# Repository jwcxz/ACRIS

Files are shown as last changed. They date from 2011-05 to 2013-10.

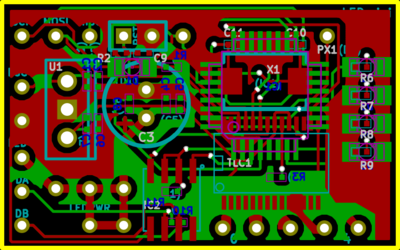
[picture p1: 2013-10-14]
boards/prj/ledmini/ledmini-brd_t.png

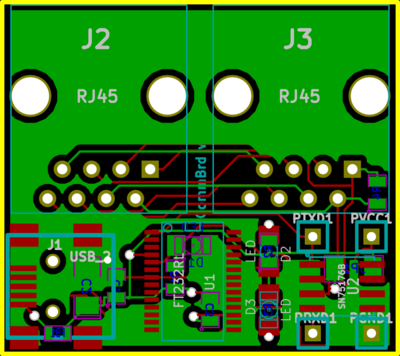
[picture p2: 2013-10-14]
boards/prj/commbrd/commbrd-brd_t.png

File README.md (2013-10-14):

ACRIS -- Advanced, Controllable Room Illumination System
========================================================

By JWC

Born out of a separate project I worked on over January and February of 2011,
[ACRIS] is a system designed to provide precise control of high-powered LEDs.
It consists of a set of LED controller boards, which drive LEDs using
constant-current sink drivers and are controlled over an RF network by a
transmitter.  This hardware is very easily controlled via simple serial
commands sent by software.

My goal for ACRIS is to provide a complete stack from base hardware to
software.

## Features

1.  Each LED controller supports up to 15 channels, with each channel sinking
    up to 360mA
2.  Each channel has 4096 levels of brightness
3.  LED controllers are around 2.3"x3.9"
4.  Status LEDs on the board show what the hell is going on
5.  LED controllers have a bootloader, so one can program new firmware to all
    devices on the bus easily.

## Repository Layout

The repository is laid out like this:

    avr     - firmware for ATmega micros on the LED controllers
    boards  - schematics and PCBs
    docs    - documents I've collected or written
    sw      - software for configuring and controlling the system

## Development

This repository has a lot of stuff that's continually being updated.  Current
effort is to convert the system to be wireless using the NRF24L01+ chip.  The
previous revision of this hardware communicated over an RS-485 network.  This,
as one might be able to imagine, proved to be really cumbersome.

[ACRIS]:http://jwcxz.com/projects/acris

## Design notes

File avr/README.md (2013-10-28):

ACRIS Firmware
==============

This directory contains firmware for the AVR MCU.  It is targeted at the
ATmega168.  The ATmega88 won't work because the bootloader is too big.

## Structure

    bld/        - configuration files for build
    inc/        - include files
    lib/        - library modules
    prj/        - projects
    Makefile    - rules for making projects from the fw dir
    README.md   - well, what are you reading?

## Projects

Projects are located in the `prj` dir.

    bootloader  - ACRIS bootloader (broken due to size issues)
    ledctrlr    - main LED controller firmware (getting there)
    rftxer      - wireless transmitter module (basic idea down)

    test-nrf    - first attempt at wireless communication with an NRF24L01+

    bootloader_uart - modified legacy bootloader that communicates over serial
    ledctrlr_uart   - modified legacy LED controller firmware, also serial

### Project structure

Each project includes:

    Makefile    - rules for making the project
    config.h    - master configuration file with project-specific rules
    pins.h      - project pinout
    main.c/h    - main project source
    README.md   - exactly what you would expect

## Libraries

There are also libraries.  In some cases, a single header can be supported by
multiple underlying designs.  Example: the `nrfspi_` module can either be
driven by the USART or the SPI module on the AVR.

    inc/ - include headers
    lib/ - library modules

    fn prefix   files       description
    __________  __________  __________________________________________________
    dbg_        dbg.h       control of board debug LEDs
                dbg.c

    eeprom_     eeprom.h    reading and writing settings in the EEPROM
                eeprom.c

    flash_      flash.h     flash memory access functions
                flash.c

    led_        led.h       action translator for LED array output
                led.c

    ledset_     ledset.h    functions for setting up TLC output buffer
                ledset.c

    nrf_        nrf.h       driver for NRF24L01+
                nrf.c

    nrfspi_     nrfspi.h    underlying data transfer layer between MCU and NRF
                nrfspi_spi.c      using HW SPI module
                nrfspi_usart.c    using USART in SPI master mode

    tlc_        tlc.h       driver for TLC5940
                tlc.c

    uart_       uart.h      UART communication layer
                uart.c

    uart_printf_    uart_printf.h   retargeting printf for uart output
                    uart_printf.c

    uart_rb_    uart_rb.h   ring-buffer com layer to make receiving streaming
                uart_rb.c   data easier

## Build

The `bld` directory contains the master rules for building projects.

## TODOs:
0.  Fix the wireless bootloader... it's too big for the flash.  This probably
    means an architectural change in reality, but at the very minimum involves
    statically linking to the end of the app-space flash or something stupid
    and dangerous like that.

1.  Install a shim between `nrf_` and the application layer to allow
    switching between wireless communication over NRF24L01+ and wired
    communication over RS-485.

2.  Add optional automatic retransmission support to the NRF driver.

3.  [partial] Update the bootloader to support wireless communication, with
    automatic retransmission to guarantee a good firmware load.

4.  Come up with a decent scheme for identifying all devices on the network and
    talking with each one of them (i.e. some kind of auto-discovery).  I have
    some ideas floating around in my head that make use of the multi-pipe
    features of the Nordic chips.

5.  Add training to startup to determine best communication channels; come up
    with a way to change network channels on the fly.

6.  Expand transmitter system to support multiple transmitters on a single host
    to boost throughput.  For extra lulz, make some run on the USART and others
    run on SPI and make the whole architecture event driven.

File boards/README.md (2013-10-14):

Electronics
===========

These schematics and boards were made with [KiCad].

## Boards

Board projects are in `prj/`.

    commbrd   - First attempt at a USB->RS485 converter
    commdngl  - USB-dongle that connects directly to a computer and delivers
                RS-485
    ecomm     - Etchable USB->RS485 converter (proven)
    ledctrlr  - The main ACRIS LED controller board
    ledmini   - Super tiny LED controller
    myropcb   - First run sent to Myro for production

## Libraries

Parts libraries (schematic symbols and footprints) are in the `libs/` dir.
Most of them are homemade, some of them are sourced from the internet.

## Tools

There are some scripts in the `tools/` dir.

    exportbom.sh  - Clean up exported BOM files
    package.sh    - Packager

### Packager
    
The packager does the following:

1.  Convert PS schematics exported from KiCad to PDF
2.  Convert SVG output from PCB editor to PNG
3.  Fix BOM headers with `exportbom.sh`
4.  Make image thumbnails.
5.  Archive Gerber and drill files
6.  Archive KiCad files 

[KiCad]:http://www.kicad-pcb.org/

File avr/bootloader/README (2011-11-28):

More information:
    http://jwcxz.com/projects/acris/bootloader.php

This bootloader provides the following features:
    1. fast startup time (i.e. bootloader->application time)
    2. downloading of program to device
    3. set address of instrument
    4. set the transmission baud rate (via the divisor)
    5. set a mask (only operate on some devices)
    6. view the instrument address on the debug LEDs
    7. program verification (not ready)

Transmission is done through a serial protocol:
    [SYNC][CMD][ARG0][ARG1]...[ARGn]

    Fn  Args    Description
    ___ _______ ____________________________________________________
    170 0       SYNC -- start of a packet

    N   0       NOP -- sent to wake bootloader up

    A   1       Set 1-byte address of the device in EEPROM

    B   2       [High][Low][Double?] -- set divisor and U2XN of the UART in EEPROM

    D   0       Show the high nibble of the instrument address on the debug LEDs

    E   0       Show the low nibble of the instrument address on the debug LEDs

    M   1       [InstAddr] Instrument address to work with for all following commands
                    0xFF - all instruments
                    0xF0-0xFE - blocks of 16

    P   2       [Addr][Page...] - Send program one page at a time
                    To simplify the bootloader, it does NOT take an Intel HEX
                    file as an input.  Rather, a special "program" script reads
                    the HEX file and outputs the following format:
                        [Starting Address][Page][Checksum]
                    The checksum is the one's complement of the sum of the
                    page stream.

                    Note: this means that the stream length depends on the page
                    size (whereas Intel HEX files have known lengths).
                    Furthermore, it requires that unused bytes be 0-filled or
                    something.  I'd rather make the programmer

    R   0       BOOT - boot the application

TODO:
    1.  Write the verification step
    2.  Allow reading bytes from EEPROM to debug LEDs
    3.  Decide whether to modify the bootloader to be able to write to and read
        from any EEPROM address

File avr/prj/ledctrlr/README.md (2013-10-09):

LED Controller Application
==========================

This is the main project of ACRIS: the firmware that runs on the LED drivers.
This version receives command packets via the UART.

## Protocol

The application-layer protocol format is: `[CMD][ARG0][ARG1]...[ARGn]`

    CMD  NAME  #ARGS ARGS / DESCRIPTION
    ____ _____ _____ _____________________________________________________
    0xAA LDSET 15    0RED 0GRN 0BLU 1RED 1GRN 1BLU ... 4RED 4GRN 4BLU
    0x00                8-bit control of each LED on the controller
                        enforces backwards compatibility with the existing
                        protocol (total 5*3*8=120 bits)
    0x01 HDSET  23   0000|0REDH 0REDL|0GRNH 0GRNL|0BLUH ...
                        12-bit packed control of each LED
                        (total 5*3*12=180 bits + 4 bits for alignment)
    0x10 LDALL  3    RED GRN BLU
                        8-bit control of all the LEDs on a given device
                        (total 3*8=24 bits)
    0x11 HDALL  5    0000|REDH REDL|GRNH ...
                        12-bit control of all the LEDs on a given device
                        (total 3*12=36 bits -> 40 bits with the firstmost
                        nibble ignored)

## Addressing

Addressing is handled in the communication layer.  It is `COM_AD_SIZE` bytes
long.  LED controllers are designed to be receivers.  Their addresses are set
in the bootloader by the EEPROM.  In the UART version, only the least
significant byte is minded.

## TODOs:

1.  Merge this into mainline wireless controller firmware and allow
    compile-time selection of the underlying communication system.

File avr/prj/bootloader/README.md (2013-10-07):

Bootloader Firmware
===================

In order to provide OTA firmware updates, I wrote a bootloader.  For more
information, see the [ACRIS bootloader page].

## Development Note

This project will require extensive modifications to support wireless
communication.  The existing wireless driver needs to support automatic
retransmission and have error modes that inform the master firmware updater
application of failures.

## Features

This bootloader provides the following features:

1.  Fast startup time (i.e. bootloader->application time)
2.  Downloading of program to device
3.  Set address of instrument
4.  Set the transmission baud rate (via the divisor)
5.  Set a mask (only operate on some devices)
6.  View the instrument address on the debug LEDs
7.  Program verification (not ready)

## Protocol

Transmission is done through a serial protocol, which looks like `[CMD][ARG0][ARG1]...[ARGn]`

    FN  ARGS    DESCRIPTION
    ___ _______ ____________________________________________________
    170 0       SYNC -- start of a packet

    N   0       NOP -- sent to wake bootloader up

    A   1       Set 1-byte address of the device in EEPROM

    B   2       [High][Low][Double?] -- set divisor and U2XN of the UART in EEPROM

    D   0       Show the high nibble of the instrument address on the debug LEDs

    E   0       Show the low nibble of the instrument address on the debug LEDs

    M   1       [InstAddr] Instrument address to work with for all following commands
                    0xFF - all instruments
                    0xF0-0xFE - blocks of 16

    P   2       [Addr][Page...] - Send program one page at a time
                    To simplify the bootloader, it does NOT take an Intel HEX
                    file as an input.  Rather, a special "program" script reads
                    the HEX file and outputs the following format:
                        [Starting Address][Page][Checksum]
                    The checksum is the one's complement of the sum of the
                    page stream.

                    Note: this means that the stream length depends on the page
                    size (whereas Intel HEX files have known lengths).
                    Furthermore, it requires that unused bytes be 0-filled or
                    something.  I'd rather make the programmer

    R   0       BOOT - boot the application

## TODOs:

1.  Enable automatic retransmission
2.  Allow reading bytes from EEPROM to debug LEDs
3.  Add ability to write to and read from any EEPROM address

[ACRIS bootloader page]:http://jwcxz.com/projects/acris/bootloader.php

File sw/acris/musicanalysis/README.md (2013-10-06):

Music Analysis
==============

This is a temporary holding directory for music analysis scripts.

there should be some sort of accessible backend that grabs an audio stream from
somewhere and converts it into a numpy array to be processed

then, there should be a series of processors that a plugin can take advantage
of.  maybe there should be some coarse-grained ones (dsp.howmuchbass()) and
some fine-grained ones (controllable-point fft)

FFT should be something to the effect of

1.  fill sample buffer
2.  apply windowing algorithm to sample set -- try hanning
3.  X = np.fft.rfft(windowed_data);
4.  Xdb = 20*np.log10(np.abs(X));
    
50% overlap between two sample buffers will likely work well

Testing with wave files:

    from scipy.io import wavfile
    fs, data = wavfile.read('/path/to/file.wav');

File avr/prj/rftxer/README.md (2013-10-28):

RF Transmitter
==============

This project essentially acts as a serial-to-RF transmitter.  Eventually it'll
be replaced by a true USB CDC module on a nice microprocessor, but for now, it
reads in a packet of data to send to a given address, and sends it.

## Protocol

The current protocol to transmit a packet is simply:

    [SYNC...][ADDR][PAYLOAD...]

The `[SYNC...]` header consists of `NUM_SYNCS` copies of `CMD_SYNC` to sync up
the serial stream.

The target address `[ADDR]` is a single byte (the LSB of the full address) for
now.  The full `COM_AD_SIZE` address space may be used later.

Since `[PAYLOAD...]` has a specific width (`COM_PL_SIZE`), the state machine is
pretty simple.

## Testing

The utility `sw/tests/nrf-dbg/nrf-txpld.py` sends test payloads to the
transmitter firmware.

## TODOs
    
1.  Allow enabling or disabling various features like auto-retransmit (useful
    for firmware updating, not useful for data streaming)

2.  Provide capability for LED controllers to report back their status in their
    ACK payloads and pass it up to the application layer.

3.  Lots of other stuff, like multiple-transmitter support.

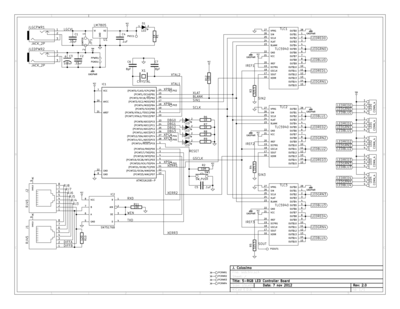
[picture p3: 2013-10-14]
boards/prj/ledctrlr/ledctrlr.png

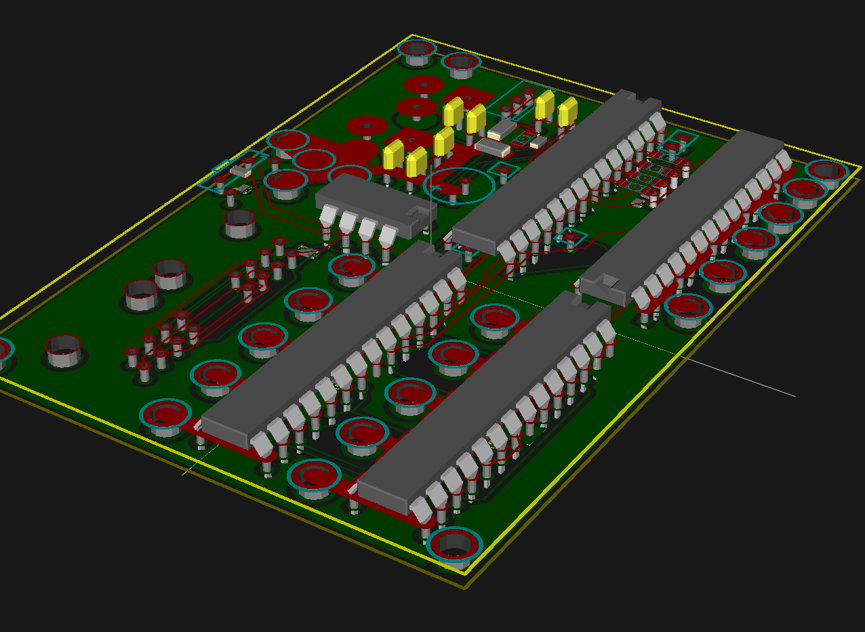
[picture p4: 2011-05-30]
boards/ledctrlr/ledctrlr-dip-routed.png

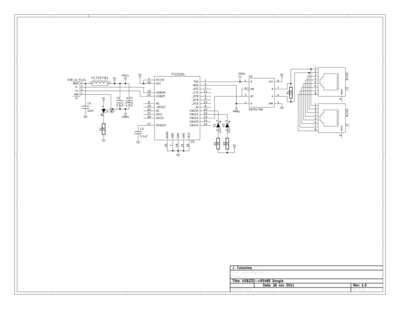
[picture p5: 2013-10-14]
boards/prj/commdngl/commdngl.png

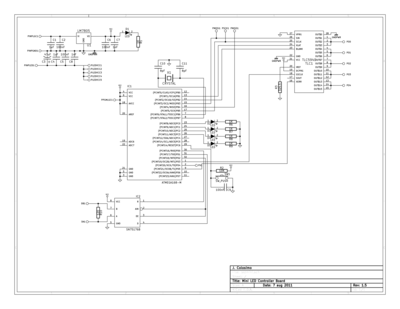
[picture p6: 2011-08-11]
boards/prj/ledmini/ledctrlr.png

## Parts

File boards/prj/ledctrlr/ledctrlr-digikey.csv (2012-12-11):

Digi-Key Part Number | Manufacturer | Manufacturer Part Number | Customer Reference | Quantity 1 | Quantity 2 | Quantity 3 | Description | Comments | RoHS Status | Lead Free Status | REACH Status
RMCF0805JT1K00CT-ND | STACKPOLE ELECTRONICS INC (VA) | RMCF0805JT1K00 | R1,6,7,8,9 | 50 | 0 | 0 | RES 1K OHM 1/8W 5% 0805 SMD |  | RoHS Compliant | Lead free | Unaffected Aug-2011
RMCF0805JT10K0CT-ND | STACKPOLE ELECTRONICS INC (VA) | RMCF0805JT10K0 | R2,11,12 | 50 | 0 | 0 | RES 10K OHM 1/8W 5% 0805 SMD |  | RoHS Compliant | Lead free | Unaffected Aug-2011
450-1662-ND | TE CONNECTIVITY ALCOSWITCH | FSMRA2JH | SW1 | 10 | 0 | 0 | SWITCH TACTILE SPST-NO 0.05A 12V |  | RoHS Compliant | Lead free | Unaffected Aug-2011
LM7805CT-ND | FAIRCHILD SEMICONDUCTOR | LM7805CT | U1 | 10 | 0 | 0 | IC REG LDO 5V 1A TO-220 |  | RoHS Compliant | Lead free | Unaffected Jun-2011
644-1026-1-ND | NDK (VA) | NX8045GB-20.000000MHZ | X1 | 10 | 0 | 0 | CRYSTAL 20.000000 MHZ 8PF SMD | Alternate Packaging Exists | RoHS Compliant | Lead free by exemption | Unaffected Nov-2011
445-1356-1-ND | TDK CORPORATION (VA) | C2012X7R1C334K/1.25 | C1,2 | 20 | 0 | 0 | CAP CER 0.33UF 16V 10% X7R 0805 |  | RoHS Compliant | Lead free | Unaffected Apr-2011
399-6103-ND | KEMET | ESK107M025AE3AA | C3 | 10 | 0 | 0 | CAP ALUM 100UF 25V 20% RADIAL |  | RoHS Compliant | Lead free | Unaffected Jan-2011
311-1361-1-ND | YAGEO (VA) | CC0805ZRY5V9BB104 | C4,5 | 25 | 0 | 0 | CAP CER 0.1UF 50V Y5V 0805 |  | RoHS Compliant | Lead free | Unaffected Sep-2011
311-1097-1-ND | YAGEO (VA) | CC0805DRNPO9BN8R0 | C6,7 | 25 | 0 | 0 | CAP CER 8PF 50V NPO 0805 |  | RoHS Compliant | Lead free | Unaffected Sep-2011
754-1142-1-ND | KINGBRIGHT CORP (VA) | APT3216SRCPRV | D1 | 10 | 0 | 0 | LED 3.2X1.6MM 640NM RED CLR SMD | Alternate Packaging Exists | RoHS Compliant | Lead free | Unaffected Feb-2011
754-1141-1-ND | KINGBRIGHT CORP (VA) | APT3216SGC | D2,3,4,5 | 50 | 0 | 0 | LED 3.2X1.6MM 568NM GRN CLR SMD |  | RoHS Compliant | Lead free | Unaffected Feb-2011
WM5572-ND | MOLEX CONNECTOR CORPORATION | 95501-2882 | J1,2 | 20 | 0 | 0 | CONN MOD JACK R/A 8P8C |  | RoHS Compliant | Lead free | Unaffected Dec-2009
CP-202A-ND | CUI INC | PJ-202A | JLGCPWER1,JLEDPWR2 | 20 | 0 | 0 | CONN POWER JACK 2.1MM PCB |  | RoHS Compliant | Lead free | Unaffected Oct-2010
ED2563-ND | ON SHORE TECHNOLOGY INC | OSTTA040161 | LED0,1,2,3,4 | 50 | 0 | 0 | TERMINAL BLOCK 5MM VERT 4POS PCB |  | RoHS Compliant | Lead free | Unaffected Aug-2011
RMCF0805JT330RCT-ND | STACKPOLE ELECTRONICS INC (VA) | RMCF0805JT330R | R3,4,5 | 50 | 0 | 0 | RES 330 OHM 1/8W 5% 0805 SMD |  | RoHS Compliant | Lead free | Unaffected Aug-2011
RMCF0805JT120RCT-ND | STACKPOLE ELECTRONICS INC (VA) | RMCF0805JT120R | R10 | 10 | 0 | 0 | RES 120 OHM 1/8W 5% 0805 SMD | Alternate Packaging Exists | RoHS Compliant | Lead free | Unaffected Aug-2011

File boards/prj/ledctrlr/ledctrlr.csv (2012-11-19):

Reference | Value | Footprint | Part | DigikeyPart | Field3 | Field4 | Field5 | Field6 | Field7 | Field8
C1 | .33uF | SM0805 | C2012X7R1C334K/1.25 | 445-1356-1-ND
C2 | .33uF | SM0805 | C2012X7R1C334K/1.25 | 445-1356-1-ND
C3 | 100uF | Elko_vert_DM7-5_RM2-5 | ESK107M025AE3AA | 399-6103-ND
C4 | .1uF | SM0805 | CC0805ZRY5V9BB104 | 311-1361-1-ND
C5 | .1uF | SM0805 | CC0805ZRY5V9BB104 | 311-1361-1-ND
C6 | 8pF | SM0805 | CC0805DRNPO9BN8R0 | 311-1097-1-ND
C7 | 8pF | SM0805 | CC0805DRNPO9BN8R0 | 311-1097-1-ND
D1 | LED | LED-1206-3D | APT3216SRCPRV | 754-1142-1-ND
D2 | LED | LED-1206-3D | APT3216SGC | 754-1141-1-ND
D3 | LED | LED-1206-3D | APT3216SGC | 754-1141-1-ND
D4 | LED | LED-1206-3D | APT3216SGC | 754-1141-1-ND
D5 | LED | LED-1206-3D | APT3216SGC | 754-1141-1-ND
IC1 | ATMEGA168-P | DIP-28__300 | ATMEGA168-20PU | ATMEGA168-20PU-ND
IC2 | SN75176B | SOIC8 | SN75176BP | 296-1739-5-ND
J1 | RJ45 | RJ45_8 | 95501-2882 | WM5572-ND
J2 | RJ45 | RJ45_8 | 95501-2882 | WM5572-ND
JLEDPWR2 | JACK_2P | JACK_ALIM | PJ-202A | CP-202A-ND
JLGCPWR1 | JACK_2P | JACK_ALIM | PJ-202A | CP-202A-ND
JP1 | JUMPER | SM1206 | N/A | N/A
LED0 | CONN_4 | OSTTA040161p | OSTTA040161 | ED2563-ND
LED1 | CONN_4 | OSTTA040161p | OSTTA040161 | ED2563-ND
LED2 | CONN_4 | OSTTA040161p | OSTTA040161 | ED2563-ND
LED3 | CONN_4 | OSTTA040161p | OSTTA040161 | ED2563-ND
LED4 | CONN_4 | OSTTA040161p | OSTTA040161 | ED2563-ND
PCRNR1 | CONN_1 | screw | N/A | N/A
PCRNR2 | CONN_1 | screw | N/A | N/A
PCRNR3 | CONN_1 | screw | N/A | N/A
PCRNR4 | CONN_1 | screw | N/A | N/A
PGND1 | CONN_1 | PAD | N/A | N/A
PPWR1 | CONN_1 | PAD
PSOUT1 | CONN_1 | PAD | N/A | N/A
PVCC1 | CONN_1 | PAD
PX1 | CONN_1 | PAD | N/A | N/A
PX2 | CONN_1 | PAD | N/A | N/A
PX3 | CONN_1 | PAD | N/A | N/A
PX4 | CONN_1 | PAD | N/A | N/A
PX5 | CONN_1 | PAD | N/A | N/A
R1 | 1K | SM0805 | RMCF0805JT1K00 | RMCF0805JT1K00CT-ND
R2 | 10K | SM0805 | RMCF0805JT10K0 | RMCF0805JT10K0CT-ND
R3 | 325.5 | SM0805 | RMCF0805JT330R | RMCF0805JT330RCT-ND
R4 | 325.5 | SM0805 | RMCF0805JT330R | RMCF0805JT330RCT-ND
R5 | 325.5 | SM0805 | RMCF0805JT330R | RMCF0805JT330RCT-ND
R6 | 1K | SM0805 | RMCF0805JT1K00 | RMCF0805JT1K00CT-ND
R7 | 1K | SM0805 | RMCF0805JT1K00 | RMCF0805JT1K00CT-ND
R8 | 1K | SM0805 | RMCF0805JT1K00 | RMCF0805JT1K00CT-ND
R9 | 1K | SM0805 | RMCF0805JT1K00 | RMCF0805JT1K00CT-ND
R10 | 120 | SM0805 | RMCF0805JT120R | RMCF0805JT120RCT-ND
R11 | 10K | SM0805 | RMCF0805JT10K0 | RMCF0805JT10K0CT-ND
R12 | 10K | SM0805 | RMCF0805JT10K0 | RMCF0805JT10K0CT-ND
SW1 | SW_PUSH | PUSH_SW | FSMRA2JH | 450-1662-ND
TLC1 | TLC5940 | DIP-28__300 | TLC5940NT | 296-17732-5-ND
TLC2 | TLC5940 | DIP-28__300 | TLC5940NT | 296-17732-5-ND
TLC3 | TLC5940 | DIP-28__300 | TLC5940NT | 296-17732-5-ND
U1 | LM7805 | LM78XXV-3D | LM7805CT | LM7805CT-ND
X1 | CRYSTAL | Crystal_FOX-FE_SMD_RevA_09Aug2010 | NX8045GB-20.000000MHZ | 644-1026-1-ND

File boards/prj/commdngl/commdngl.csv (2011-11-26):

Reference | Value | Footprint | Part | DigikeyPart
C1 | 0.1uF | SM0805 | CC0805ZRY5V9BB104 | 311-1361-1-ND
C2 | 4.7uF | SM0805 | F921A475MPA | 493-2333-1-ND
C3 | 0.1uF | SM0805 | CC0805ZRY5V9BB104 | 311-1361-1-ND
C4 | 10nF | SM0603 | C1608X7R1H103K | 445-1311-1-ND
D1 | LED | SM1206 | APT3216SRCPRV | 754-1142-1-ND
D2 | LED | LED-1206 | APT3216SGC | 754-1141-1-ND
D3 | LED | LED-1206 | APT3216SGC | 754-1141-1-ND
FB1 | FILTER | SM0603 | MMZ1608S400A | 445-2183-1-ND
J1 | USB-A-PLUG | USB-A-PLUG | 48037-0001 | WM17117-ND
J2 | RJ45 | RJ45_8
J3 | RJ45 | RJ45_8 | 95501-2882 | WM5572-ND
PGND1 | CONN_1 | SIL-1 | N/A | N/A
PRXD1 | CONN_1 | SIL-1 | N/A | N/A
PTXD1 | CONN_1 | SIL-1 | N/A | N/A
PVCC1 | CONN_1 | SIL-1 | N/A | N/A
R1 | 1K | SM0805 | RMCF0805JT1K00 | RMCF0805JT1K00CT-ND
R2 | 1K | SM0805 | RMCF0805JT1K00 | RMCF0805JT1K00CT-ND
R3 | 1K | SM0805 | RMCF0805JT1K00 | RMCF0805JT1K00CT-ND
R4 | 120 | SM0805 | RMCF0805JT120R | RMCF0805JT120RCT-ND
U1 | FT232RL | SSOP28 | FT232RL-REEL | 768-1007-1-ND
U2 | SN75176B | SOIC8 | SN75176BPSR | 296-27995-1-ND

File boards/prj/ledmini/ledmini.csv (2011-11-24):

Reference | Value | Footprint | Part | DigikeyPart
C1 | 1uF | SM0402 | C1005X5R0J105M | 445-1415-1-ND
C2 | 100nF | SM0402 | C1005Y5V1E104Z | 445-3445-1-ND
C3 | 47uF | Elko_vert_DM7-5_RM2-5 | ECA-1CM470 | P5137-ND
C4 | 1uF | SM0402 | C1005X5R0J105M | 445-1415-1-ND
C5 | 100nF | SM0402 | C1005Y5V1E104Z | 445-3445-1-ND
C6 | 100nF | SM0402 | C1005Y5V1E104Z | 445-3445-1-ND
C7 | 1nF | SM0402 | C1005X7R1H102K | 445-1256-1-ND
C8 | 1nF | SM0402 | C1005X7R1H102K | 445-1256-1-ND
C9 | 100nF | SM0402 | C1005Y5V1E104Z | 445-3445-1-ND
C10 | 8pF | SM0402 | C1005C0G1H080D | 445-4891-1-ND
C11 | 8pF | SM0402 | C1005C0G1H080D | 445-4891-1-ND
D1 | LED | LED-1206 | APT3216SRCPRV | 754-1142-1-ND
D2 | LED | LED-1206 | APT3216SGC | 754-1141-1-ND
D3 | LED | LED-1206 | APT3216SGC | 754-1141-1-ND
D4 | LED | LED-1206 | APT3216SGC | 754-1141-1-ND
D5 | LED | LED-1206 | APT3216SGC | 754-1141-1-ND
DA1 | CONN_1 | 1pin | N/A | N/A
DB1 | CONN_1 | 1pin | N/A | N/A
IC1 | ATMEGA168-M | TQFP32 | ATMEGA168P-20AU | ATMEGA168P-20AU-ND
IC2 | SN75176B | SOIC8 | SN75176BD | 296-1275-5-ND
PINPGND1 | CONN_1 | 1pin | N/A | N/A
PINPLED1 | CONN_1 | 1pin | N/A | N/A
PINPLGC1 | CONN_1 | 1pin | N/A | N/A
PLEDVCC1 | CONN_1 | SIL-1 | N/A | N/A
PLEDVCC2 | CONN_1 | SIL-1 | N/A | N/A
PLEDVCC3 | CONN_1 | SIL-1 | N/A | N/A
PLEDVCC4 | CONN_1 | SIL-1 | N/A | N/A
PLEDVCC5 | CONN_1 | SIL-1 | N/A | N/A
PMISO1 | CONN_1 | SIL-1 | N/A | N/A
PMOSI1 | CONN_1 | SIL-1 | N/A | N/A
PO0 | CONN_1 | 1pin | N/A | N/A
PO1 | CONN_1 | 1pin | N/A | N/A
PO2 | CONN_1 | 1pin | N/A | N/A
PO3 | CONN_1 | 1pin | N/A | N/A
PO4 | CONN_1 | 1pin | N/A | N/A
PPGMLGC1 | CONN_1 | 1pin | N/A | N/A
PSCK1 | CONN_1 | SIL-1 | N/A | N/A
PX1 | CONN_1 | SIL-1 | N/A | N/A
R1 | 1K | SM0402 | RMCF0402JT1K00 | RMCF0402JT1K00CT-ND
R2 | 10K | SM0402 | RMCF0402JT10K0 | RMCF0402JT10K0CT-ND
R3 | 325.5 | SM0402 | P330JCT-ND | ERJ-2GEJ331X
R6 | 1K | SM0402 | RMCF0402JT1K00 | RMCF0402JT1K00CT-ND
R7 | 1K | SM0402 | RMCF0402JT1K00 | RMCF0402JT1K00CT-ND
R8 | 1K | SM0402 | RMCF0402JT1K00 | RMCF0402JT1K00CT-ND
R9 | 1K | SM0402 | RMCF0402JT1K00 | RMCF0402JT1K00CT-ND
R10 | 120 | SM0402 | ERJ-2GEJ121X | P120JCT-ND
R11 | 10K |  | RMCF0402JT10K0 | RMCF0402JT10K0CT-ND
SW1 | SW_PUSH | PUSH_SW | FSMRA2JH | 450-1662-ND
TLC1 | TLC5940 | SSOP28 | TLC5940PWP | 296-17733-5-ND
U1 | LM7805 | LM78XXV | LM7805CT | LM7805CT-ND
X1 | CRYSTAL | Crystal_FOX-FE_SMD_RevA_09Aug2010 | NX8045GB-20.000000MHZ | 644-1026-1-ND

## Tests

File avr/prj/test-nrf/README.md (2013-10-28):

Test FW: Wireless Communication
===============================

This is a highly-configurable testing firmware that interacts with the
NRF24L01+ to send or receive data.  The relative build parameters to pass to
`make` are `MODE` and `TRGT`.

## Transmitter target

When building with `MODE=tx TRGT=breadboard` (`TRGT=ledctrlr` untested),
firmware that simply sends payloads of incrementing values to the fixed
receiver address of `0xAAAA01`.  The transmitter's own address is `0x555501`,
but this is irrelevant.

## Receiver target

The receiver listens for incoming packets and happily blinks LEDs when it
receives them.  There are two options for building with `MODE=rx`.

### Breadboard setup

Building with `TRGT=breadboard` produces firmware that is designed to operate
with the NRF24L01+ on the eral SPI bus and a serial console on the UART.  A
serial bootloader must be installed on the chip.

The firmware spits out received packets to the UART for inspection.
`sw/tests/nrf-dbg/nrf-cap.py` is useful here.

### Reworked ACRIS board setup

Building with `TRGT=ledctrlr` produces firmware that is designed for reworked
ACRIS LED controllers.  The NRF24L01+ is attached to the USART and the boards
are programmed directly over JTAG.

Therefore, no UART output is available, but you can watch the debug LEDs
happily blink received packets.

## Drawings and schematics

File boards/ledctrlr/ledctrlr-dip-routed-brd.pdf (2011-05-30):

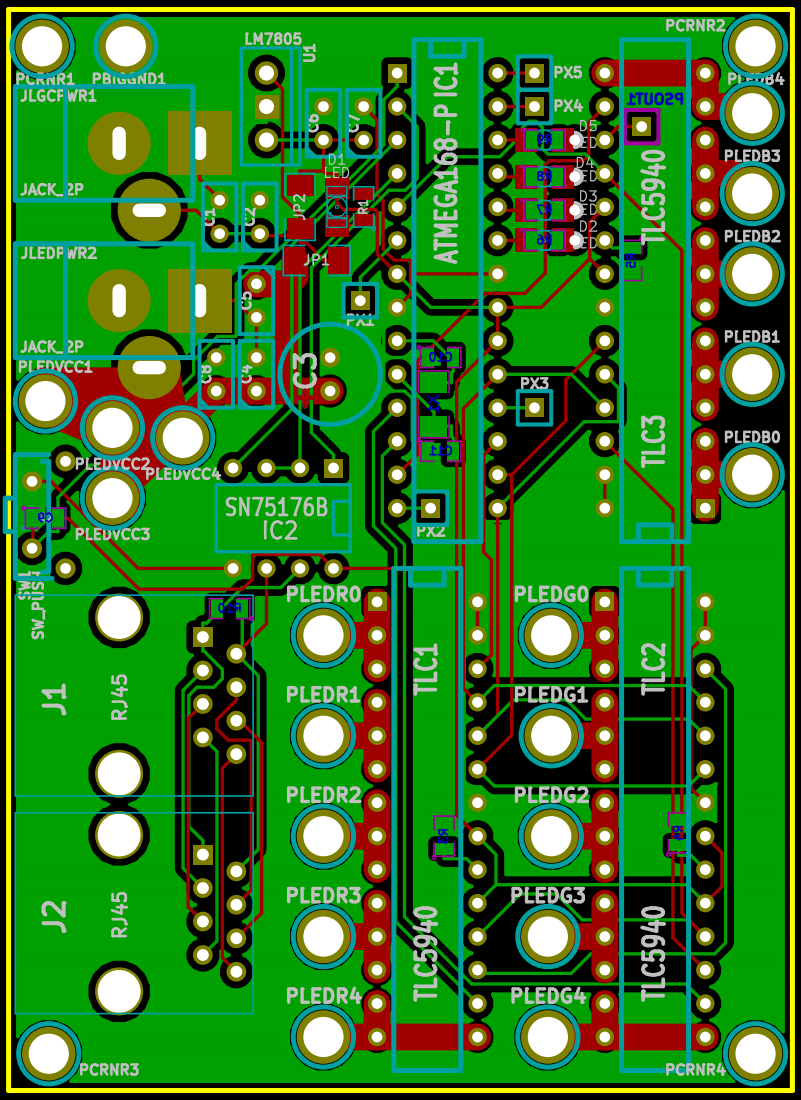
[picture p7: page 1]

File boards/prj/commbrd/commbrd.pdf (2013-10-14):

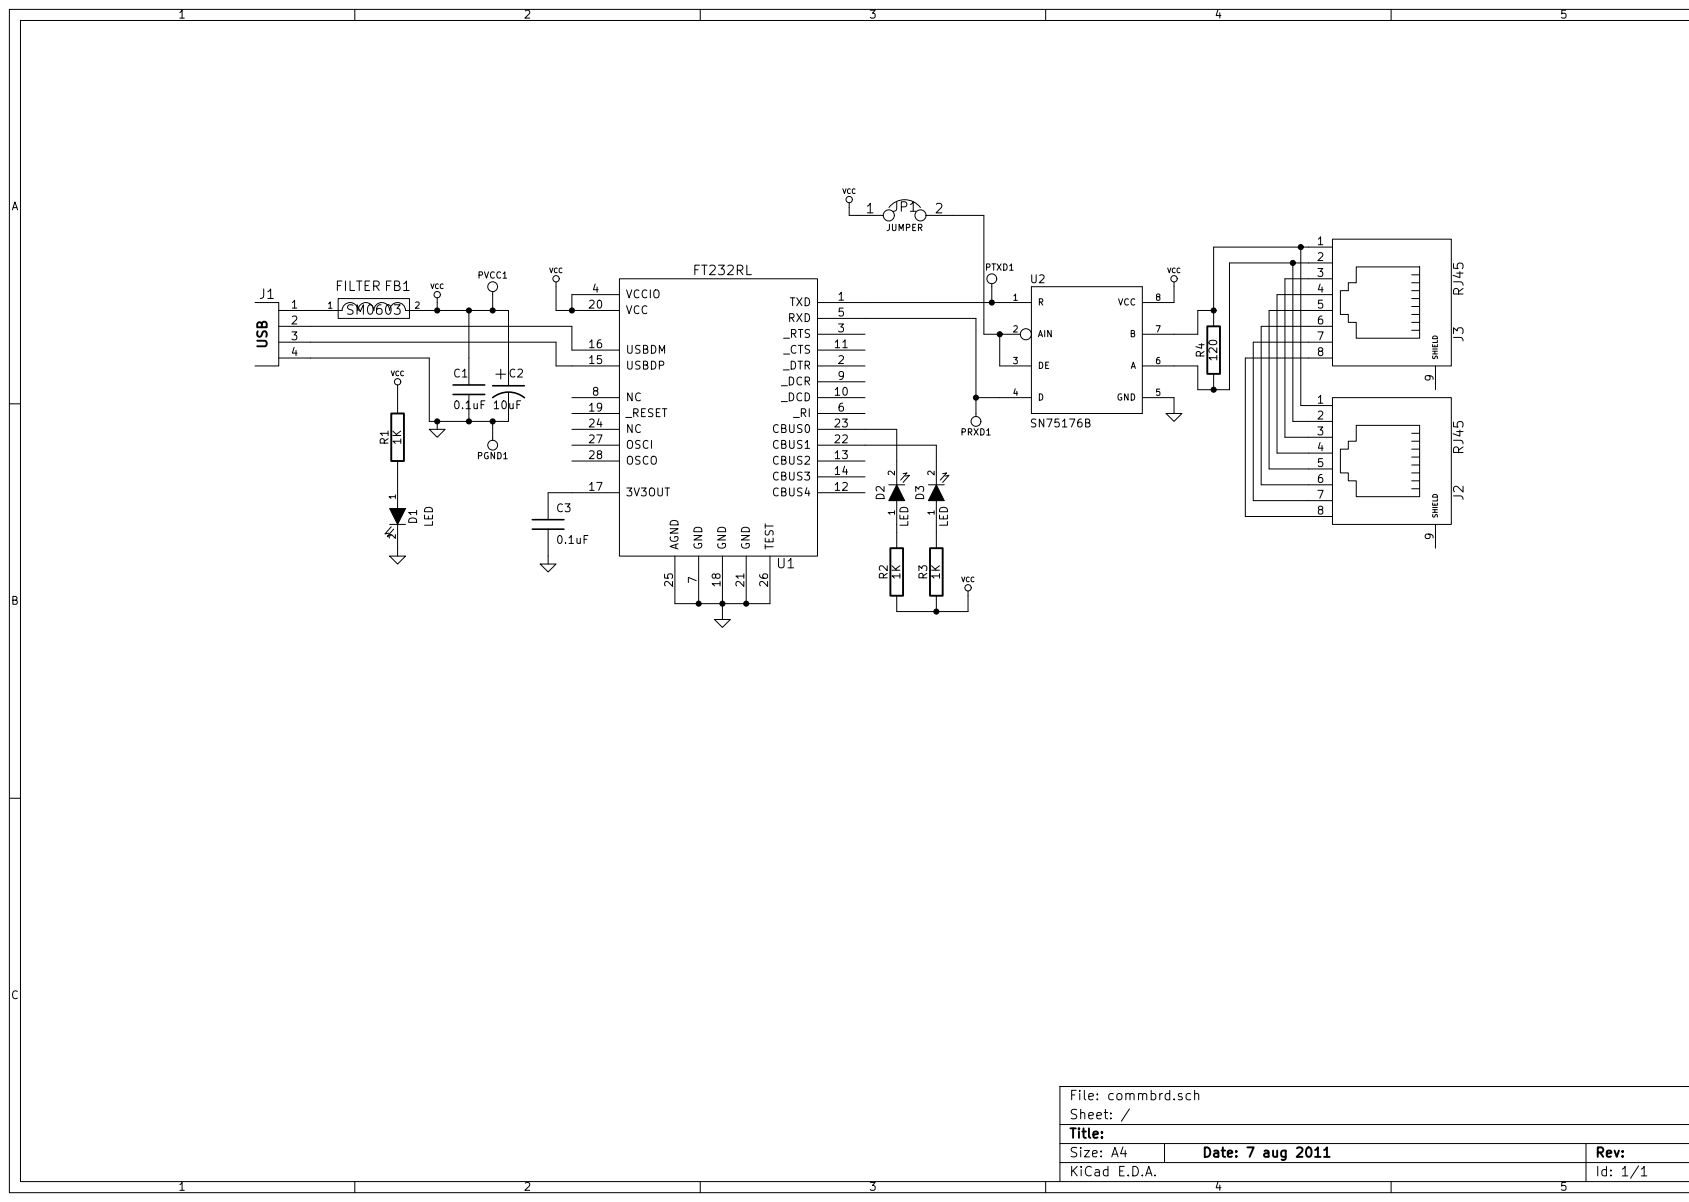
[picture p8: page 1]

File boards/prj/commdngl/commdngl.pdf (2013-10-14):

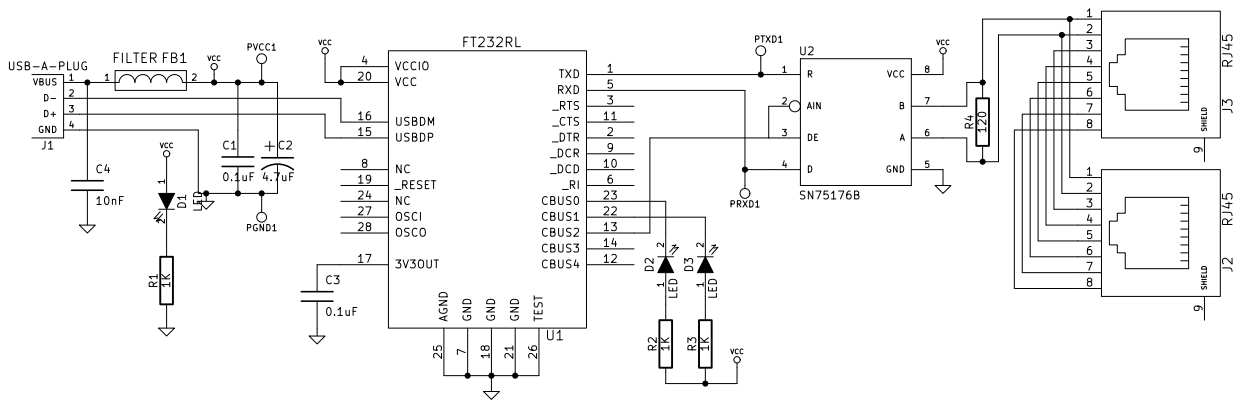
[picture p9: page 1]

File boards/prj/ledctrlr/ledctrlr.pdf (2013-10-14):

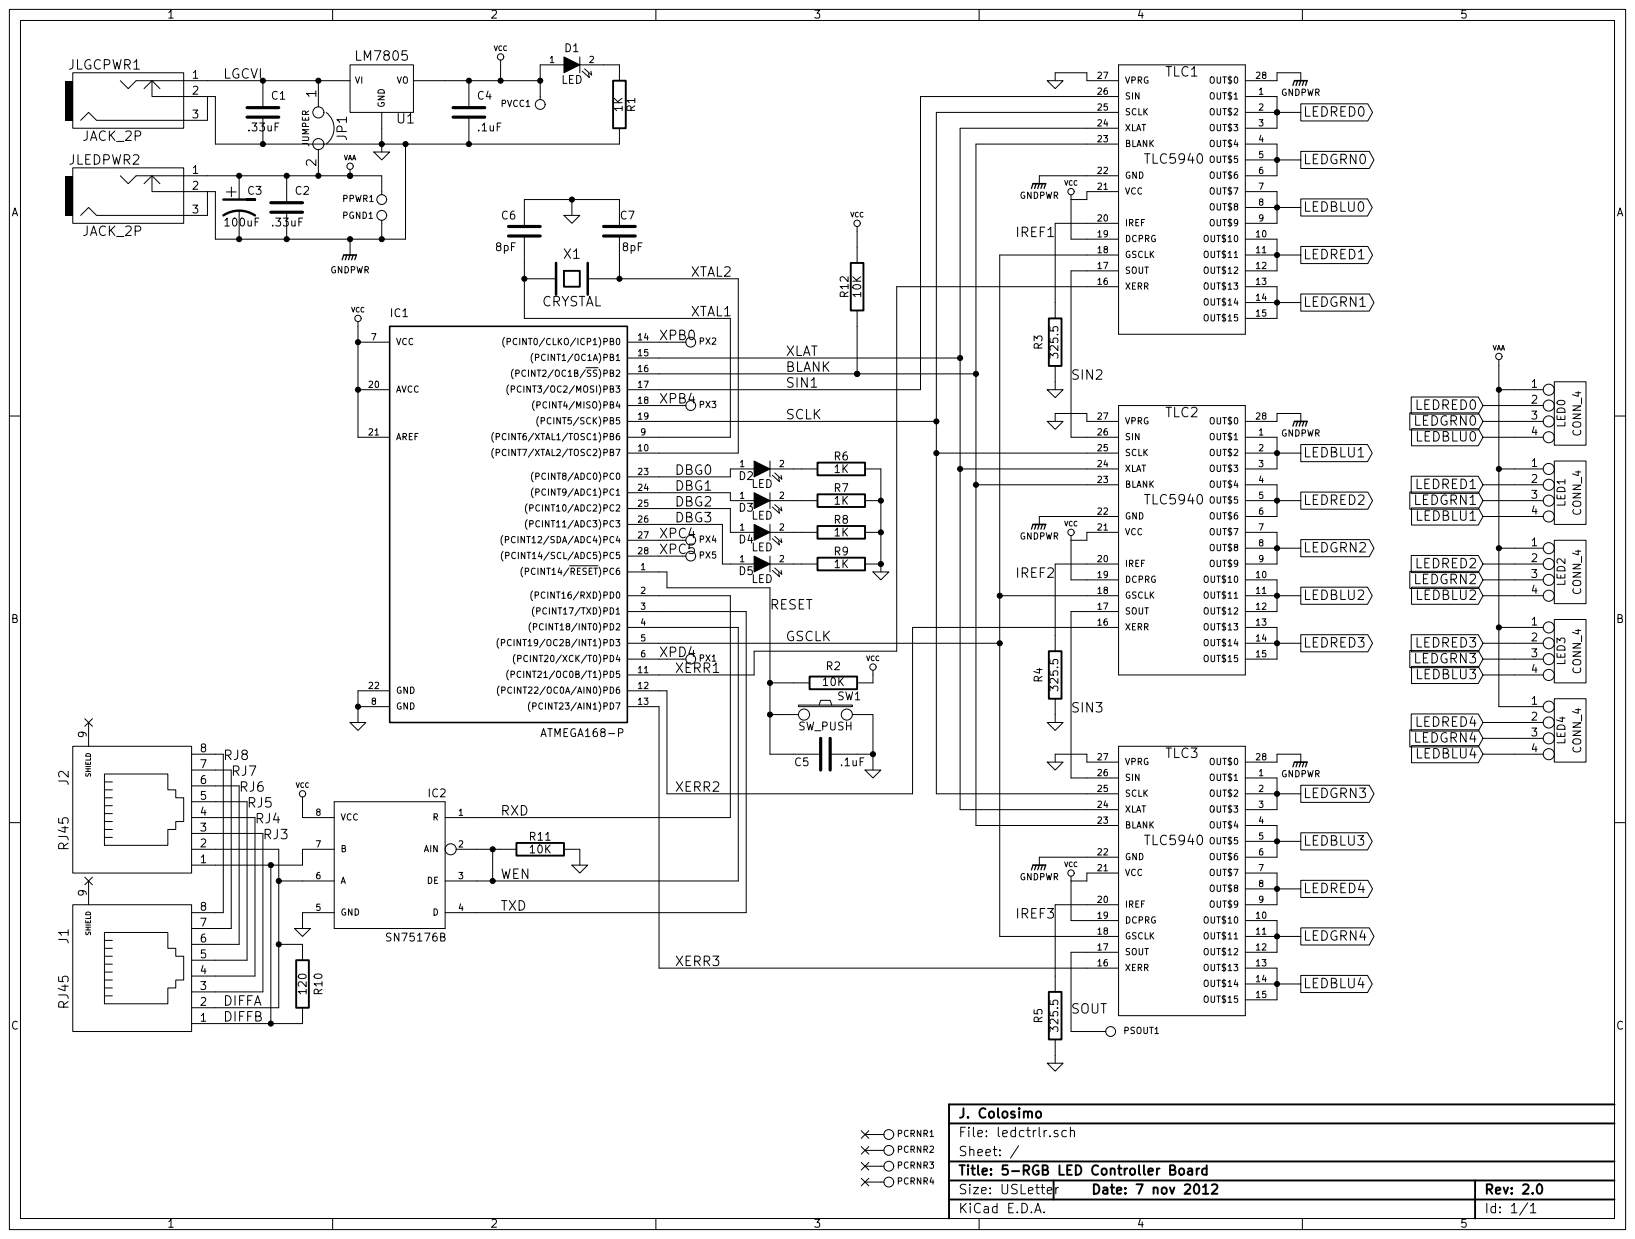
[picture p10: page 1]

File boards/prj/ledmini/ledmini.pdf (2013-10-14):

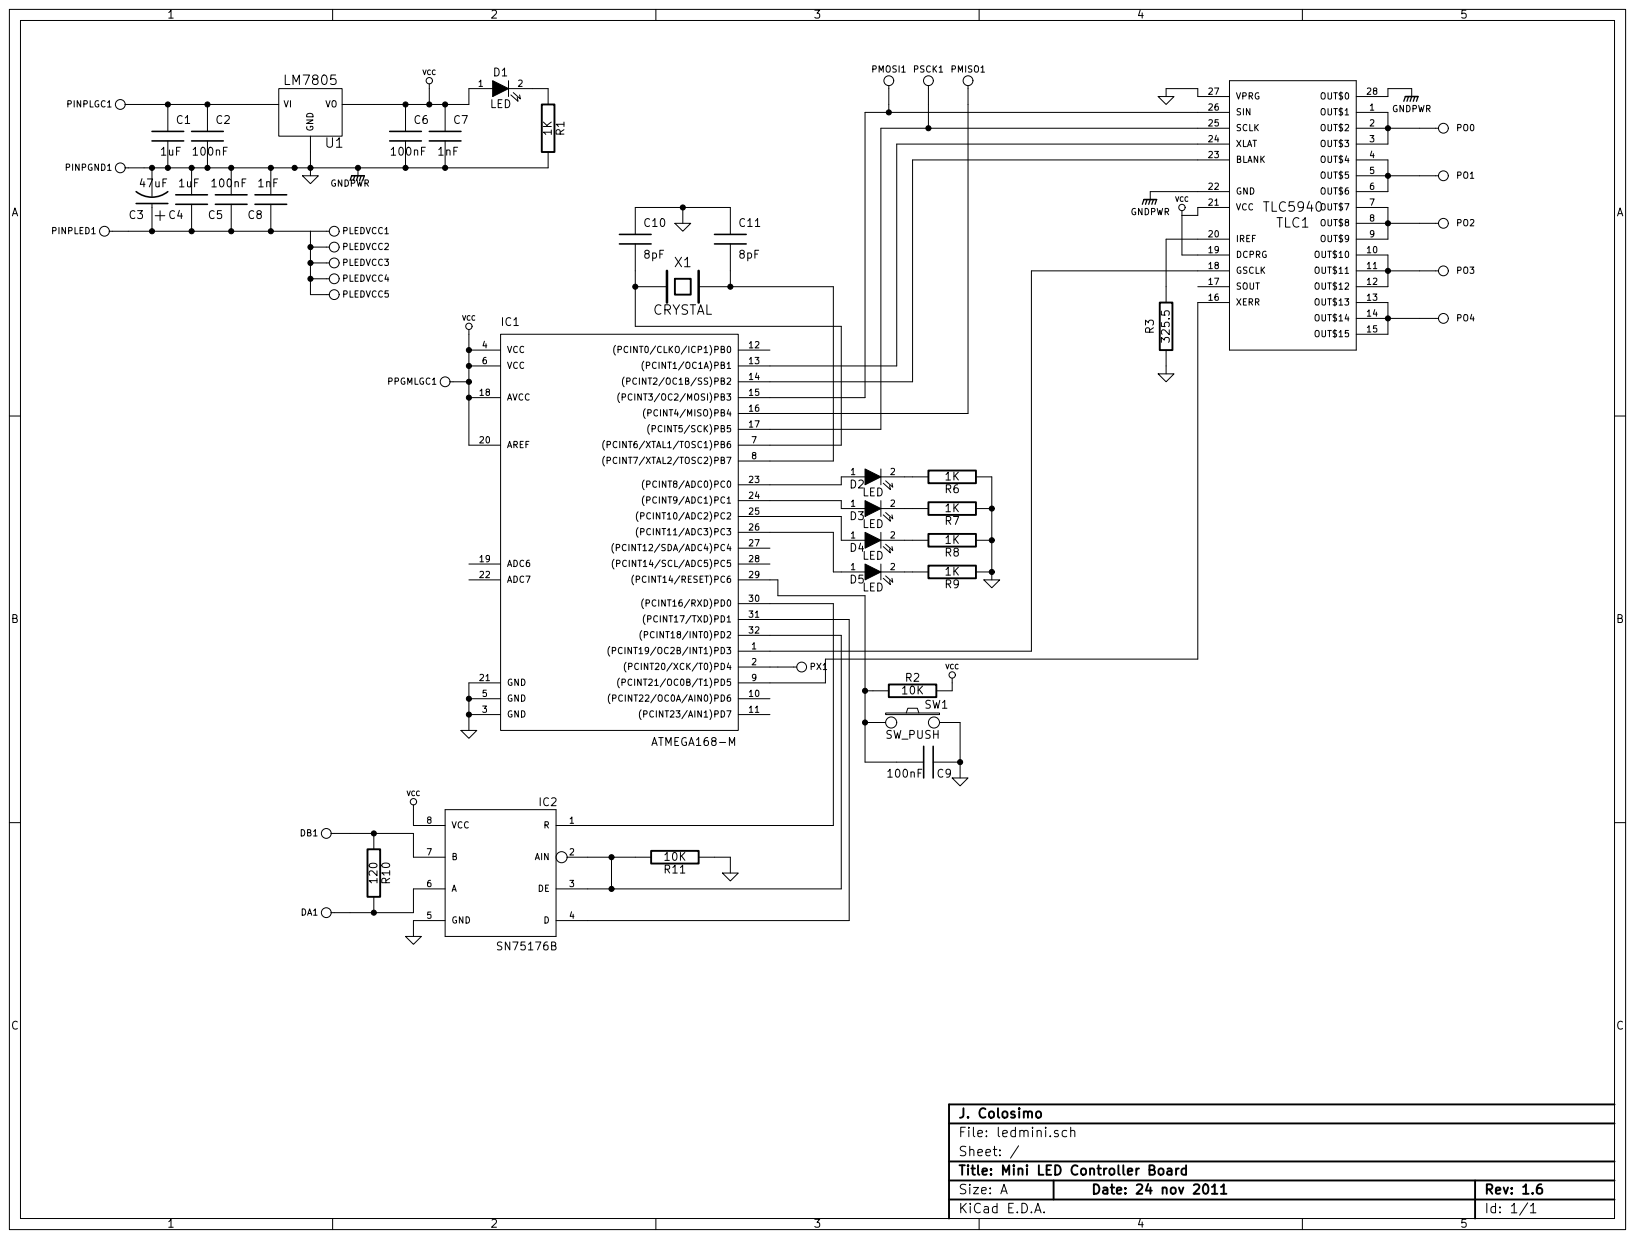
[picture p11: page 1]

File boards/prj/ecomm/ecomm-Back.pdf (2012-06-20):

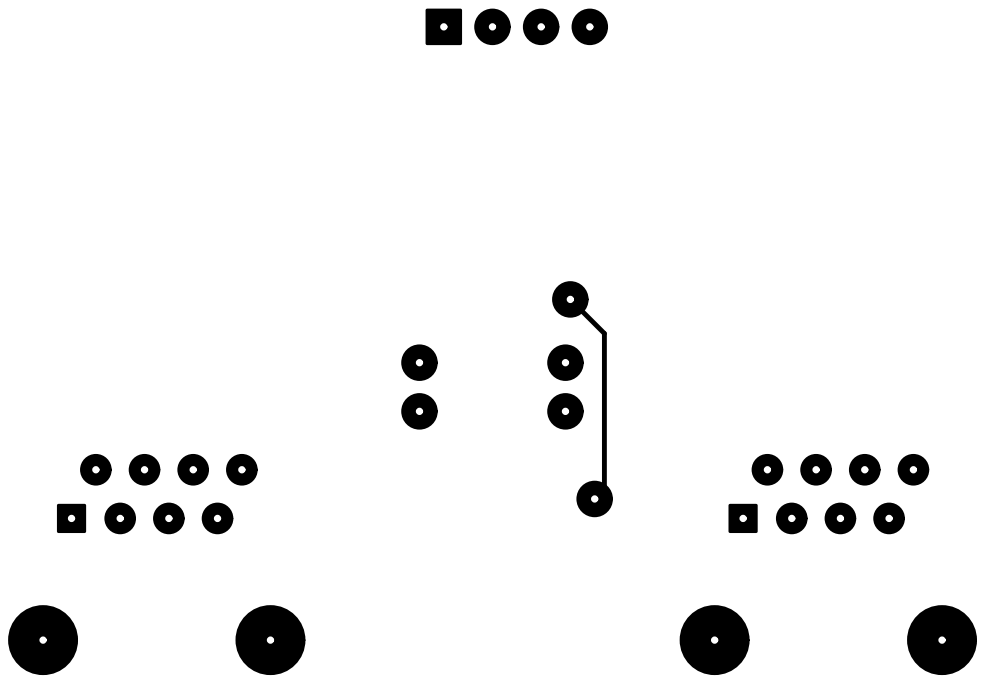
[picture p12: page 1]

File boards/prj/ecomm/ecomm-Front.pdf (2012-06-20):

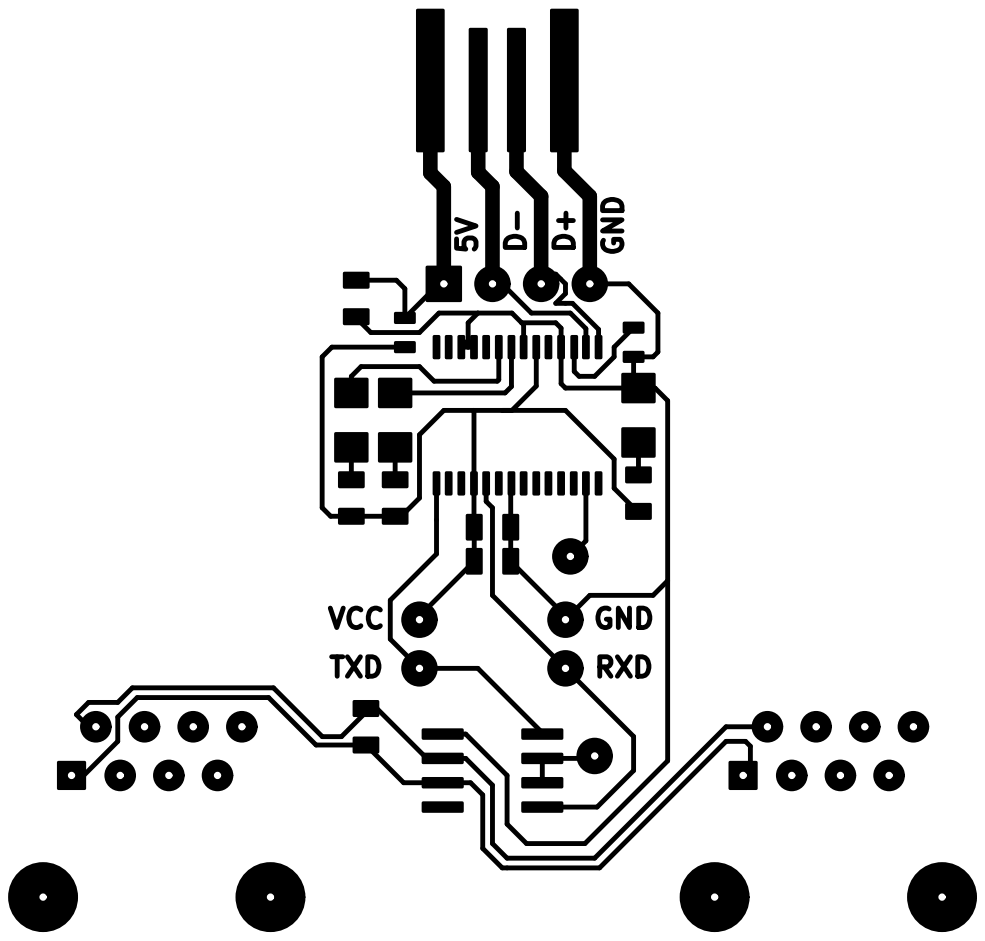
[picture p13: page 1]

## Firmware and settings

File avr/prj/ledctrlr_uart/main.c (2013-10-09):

/* A C R I S   P R O J E C T
 * LED Controller Firmware
 * http://jwcxz.com/projects/acris
 * jwc :: jwcxz.com
 */

#include "config.h"

#include <inttypes.h>
#include <util/delay.h>
#include <avr/io.h>
#include <avr/interrupt.h>
#include <avr/pgmspace.h>
#include <avr/boot.h>
#include <avr/eeprom.h>

#include "main.h"

#include "dbg.h"
#include "eeprom.h"
#include "led.h"
#include "tlc.h"
#include "uart.h"
#include "uart_rb.h"

uint8_t my_addr_full[3];
uint8_t my_addr;

// TODO: un-extern this
uint8_t tlc[3][24];

uint8_t action;         // current action
uint8_t numargs;        // number of arguments to expect
uint8_t args[MAXARGS];  // array to store arguments
uint8_t *argptr = args; //   ... associated pointer

static uint8_t cmdstate;

int main(void) {
    // initialize debug LEDs
    dbg_init();
    dbg_set(0x8);

    // initialize TLC
    tlc_init();
    // set everything off
    //tlc_drive();

    // get the address of the device
    eeprom_get_addr(my_addr_full);
    my_addr = my_addr_full[0];

    // initialize UART
    uart_rb_init();
    
    // enable interrupts
    sei();

    while (1) {
        if ( uart_rb_data_rdy() ) {
            receive_data();
        }
    }

	return 0;
}

void receive_data(void) {
    unsigned char inbyte;

    inbyte = uart_rb_rx();

    if ( inbyte == CMD_SYNC )  {
        // the sync byte is always treated as a trigger to reset the state
        // machine -- never send it as an argument
        cmdstate = CST_SYNC;
    } else {
        switch (cmdstate) {
            case CST_IDLE:
                cmdstate = CST_IDLE;
                break;
                
            case CST_SYNC:
                // save command for later processing
                action = inbyte;
                
                // reset arg pointer
                argptr = args;

                switch (inbyte) {
                    case CMD_LDSET:
                    case CMD_LDSET_LEGACY:
                        dbg_set(0x4);
                        action = CMD_LDSET; // replace legacy action code
                        numargs = 16;
                        cmdstate = CST_ARGS;
                        break;

                    case CMD_HDSET:
                        dbg_set(0x4|0x1);
                        numargs = 24;
                        cmdstate = CST_ARGS;
                        break;

                    case CMD_LDALL:
                        dbg_set(0x2);
                        numargs = 24;
                        numargs = 4;
                        cmdstate = CST_ARGS;
                        break;

                    case CMD_HDALL:
                        dbg_set(0x2|0x1);
                        numargs = 6;
                        cmdstate = CST_ARGS;
                        break;
                        
                    case CMD_STATS:
                        dbg_set(0x8);
                        numargs = 1;
                        cmdstate = CST_ARGS;
                        break;

                    default:
                        cmdstate = CST_IDLE;
                        break;
                }
                break;

            case CST_ARGS:
                *argptr++ = inbyte;

                if ( argptr - args == numargs ) {
                    // all arguments collected
                    // perform appropriate action
                    
#if 1
                    led_action(action, args);
#else
                    if (action == CMD_STATS) {
                        // send back system status
                        if (my_addr == args[0]) {
                            uart_tx(tlc_read_xerr());
                        }
                    } else {
                        led_action(action, args);
                    }
#endif

                    cmdstate = CST_IDLE;
                } else {
                    cmdstate = CST_ARGS;
                }
                break;

            default:
                // the hell!?
                cmdstate = CST_IDLE;
                break;
        }
    }
}

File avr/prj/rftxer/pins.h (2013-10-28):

#ifndef __PINS_H_
#define __PINS_H_


// UART
#define UART_TX_PIN  PD1
#define UART_TX_PRT  PORTD
#define UART_TX_DDR  DDRD

#define UART_RX_PIN  PD0
#define UART_RX_PRT  PORTD
#define UART_RX_DDR  DDRD


// NRF24L01+ control and data
// IRQ
#define NRF_IRQ_PIN  PD2
#define NRF_IRQ_PRT  PORTD
#define NRF_IRQ_DDR  DDRD

// chip enable
#define NRF_CE_PIN   PB0
#define NRF_CE_PRT   PORTB
#define NRF_CE_DDR   DDRB

// SPI CS_L
#define NRF_CSN_PIN  PC4
#define NRF_CSN_PRT  PORTC
#define NRF_CSN_DDR  DDRC

// MISO
#define NRF_MISO_PIN PB4
#define NRF_MISO_PRT PORTB
#define NRF_MISO_DDR DDRB

// MOSI
#define NRF_MOSI_PIN PB3
#define NRF_MOSI_PRT PORTB
#define NRF_MOSI_DDR DDRB

// SCLK
#define NRF_SCLK_PIN PB5
#define NRF_SCLK_PRT PORTB
#define NRF_SCLK_DDR DDRB

// SS
#define NRF_CSEL_PIN PB2
#define NRF_CSEL_PRT PORTB
#define NRF_CSEL_DDR DDRB


// debug
#define DBGLED_MSK  0x0F
#define DBGLED_PRT  PORTC
#define DBGLED_DDR  DDRC


#endif

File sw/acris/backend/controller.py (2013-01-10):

from backend.network import Commands as cmd
import backend.utils

class Controller:
    mode = "ld";

    def __init__(self, network, address):
        self.network = network; # serial connection
        self.address = address; # device address
        
    def set_mode(self, newmode):
        if newmode == "hd":
            self.mode = "hd";
        elif newmode == "ld":
            self.mode = "ld";

    def set(self, args):
        if self.mode == "ld":
            self.ldset(args);
        else:
            self.hdset(args);

    def hdset(self, args):
        packedargs = backend.utils.hdpack(args);
        self.network.cmd([cmd.HDSET, self.address]+packedargs);

    def ldset(self, args):
        packedargs = [];

        for i in xrange(5):
            packedargs.extend(args[i]);

        self.network.cmd([cmd.LDSET, self.address]+packedargs);

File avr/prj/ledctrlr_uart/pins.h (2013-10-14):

#ifndef __PINS_H_
#define __PINS_H_


// UART communication
#define UART_TX_PIN    PD1
#define UART_TX_PRT    PORTD
#define UART_TX_DDR    DDRD

#define UART_RX_PIN    PD0
#define UART_RX_PRT    PORTD
#define UART_RX_DDR    DDRD


// NRF24L01+ control and data
// IRQ
#define NRF_IRQ_PIN  PD2
#define NRF_IRQ_PRT  PORTD
#define NRF_IRQ_DDR  DDRD

// chip enable
#define NRF_CE_PIN   PB0
#define NRF_CE_PRT   PORTB
#define NRF_CE_DDR   DDRB

// SPI CS_L
#define NRF_CSN_PIN  PC4
#define NRF_CSN_PRT  PORTC
#define NRF_CSN_DDR  DDRC

// MISO
#define NRF_MISO_PIN PD0
#define NRF_MISO_PRT PORTD
#define NRF_MISO_DDR DDRD

// MOSI
#define NRF_MOSI_PIN PD1
#define NRF_MOSI_PRT PORTD
#define NRF_MOSI_DDR DDRD

// SCLK
#define NRF_SCLK_PIN PD4
#define NRF_SCLK_PRT PORTD
#define NRF_SCLK_DDR DDRD


// debug
#define DBGLED_MSK  0x0F
#define DBGLED_PRT  PORTC
#define DBGLED_DDR  DDRC


// TLC data
#define TLC_MOSI_PIN    PB3
#define TLC_SCLK_PIN    PB5
#define TLC_SDSS_PIN    PB2
#define TLC_DATA_PRT    PORTB
#define TLC_DATA_DDR    DDRB


// TLC control
#define TLC_GSCLK_PIN   PD3
#define TLC_GSCLK_PRT   PORTD
#define TLC_GSCLK_DDR   DDRD

#define TLC_XLAT_PIN    PB1
#define TLC_BLANK_PIN   PB2
#define TLC_CTRL_PRT    PORTB
#define TLC_CTRL_DDR    DDRB


// TLC error
#define TLC_XERR1_PIN   PD5
#define TLC_XERR2_PIN   PD6
#define TLC_XERR3_PIN   PD7
#define TLC_XERRS_MSK   (_BV(TLC_XERR1_PIN) | _BV(TLC_XERR2_PIN) | _BV(TLC_XERR3_PIN))
#define TLC_XERR_PIN    PIND
#define TLC_XERR_PRT    PORTD
#define TLC_XERR_DDR    DDRD


#endif

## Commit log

2011-05-25 finished version 1.5 of the schematics; started a test board design
    [$savepcb.brd, ledctrlr.brd, ledctrlr.dsn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]
2011-05-30 done with first draft
    [$savepcb.brd, ledctrlr-dip-routed.brd, ledctrlr-dip.brd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]
2011-06-01 board updates
    [$savepcb.brd, commbrd-unrouted.brd, commbrd.brd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]
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2011-06-13 added footprints, part numbers, digikey part numbers
    [commbrd-bom.csv, commbrd.sch]
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2011-06-14 added ground plane, exported gerbers, etc., created export folder
    [$savepcb.brd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]
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2011-06-17 modified command handler to be more efficient with the current setup
    old stuff was left in case I want to add more commands (e.g. strobing)
2011-06-17 final draft of the boards
    [ledctrlr-Back.gbl, ledctrlr-Front.gtl, ledctrlr-Mask_Back.gbs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]
2011-07-03 fixed some more stuff
    [main.c, main.h]
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2011-07-14 finished board test, bootloader almost ready (keeps crashing)
    [bootlib.py, main.c, main.h]
2011-07-18 fixed regular board, added mini board
    [$savepcb.brd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]
2011-07-21 finished draft of board panel layouts
    [myropcb-comm-Back.gbl, myropcb-comm-Front.gtl, myropcb-comm-Mask_Back.gbs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]
2011-07-23 removed temporary files, cleaning shit up so things look good
    [$savepcb.brd]
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2011-08-11 finished ledmini, controller, and comm boards -- need to re-panelize myro boards
    [commbrd-Back.gbl, commbrd-Front.gtl, commbrd-Mask_Back.gbs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]
2011-08-11 finished myro layouts
    [$savepcb.brd, commbrd-append.brd, ledmini-append.brd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]
2011-08-14 finished all boards, prepared myropcb order and sent it out for processing
    [$savepcb.brd, commbrd-append.brd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]
2011-08-23 fixed 485 set read mode, fixed nops being read all the time
    [main.c]
2011-08-23 added writeserial option to Makefile, fixed bootloader to support setting baud rate correctly, added helper shell script for programming
    [bootloader.py]
2011-08-23 played with debug leds, fixed double issue, moved tlc_init to top
    [main.c]
2011-08-29 Changed bootloader writefuse to work again, formatting issue in ledctrlr/main.c, and revamped acris software to be highly modular and easy to program for
    [bootlib.py, bootloader.py, controller.py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]
2011-09-04 Reworked the system so that there's a master server that can dynamically read data from plugins and stuff. Began basic interface work, but that's not ready yet. It's getting pretty awesome now. :)
    [controller.py, network.py, utils.py]
2011-09-05 fixed baud rate help in bootloader.py -h
    [bootloader.py]
2011-09-05 fixed capitalization of baud and double arguments
    [bootloader.py]
2011-09-22 fixed failure to detect sync in command args
    [network.py]
2011-11-23 ignore .*
    [ledctrlr.brd, ledctrlr.sch]
2011-11-23 ignore $savepcb.*, fix board issues (power connector, reset button hole size, data enable pulldown
    [ledctrlr.brd, ledctrlr.sch]
2011-11-24 Revision 1.6 of boards ready (silkscreen fixes), modified package script to convert SVG->PNG automatically (SVG->PDF doesn't work D:).
    [ledctrlr-bom.csv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]
2011-11-26 Created USB RS485 dongle board, fixed connector on communications board, re-exported everything
    (I should probably .gitignore the results of boards/package.sh)
    [commbrd-unrouted.brd, commbrd.brd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]
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2011-11-28 Added keepalive plugin.
    I have a sneaking suspicion that my serial controller might be doing
    something weird because when I stop sending data and then try again a
    few hours later, I have to reset the lights. Part of the problem is
    probably the lack of a pulldown resistor on the data enable line of the
    SN75176B. But this might help mitigate the issue as well by sending an
    "off" packet every second.
2011-12-26 added screw terminals, no work done
    [ledctrlr.brd, ledctrlr.sch]
2012-02-05 IMPORTANT: fixes the freezing communication bug once and for all (?)
    [main.c, uart.c]
2012-03-21 working on new version
    [ledctrlr.brd, ledctrlr.sch]
2012-03-21 adding 3D components
    [ledctrlr.brd, ledctrlr.sch]
2012-03-22 Potential new board layout... needs routing
    [ledctrlr.brd, ledctrlr.sch]
2012-03-25 placement of v2.0 boards almost done
    [commbrd.csv, commdngl.csv, ledctrlr-bom.csv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]
2012-03-25 ran into unroutable issue, I think -- try with freeroute
    [ledctrlr.brd, ledctrlr.dsn, ledctrlr.sch]
2012-03-31 fixed smd tlc5940s
    [ledctrlr.brd, ledctrlr.dsn, ledctrlr.sch]
2012-04-01 working on board layout moar
    [ledctrlr.brd, ledctrlr.sch]
2012-06-20 added ecomm -- etchable comm board
    [ecomm.brd, ecomm.sch]
2012-06-20 finished ecomm -- ready for etching
    [ecomm.brd]
2012-08-30 add multiple simultaneous plugin support
    The ACRIS server can now activate and stop any number of plugins so long
    as they don't try to access the same devices (potential TODO: add
    overriding or something).
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2012-10-29 begin ripup and design of new boards
    [ledctrlr.brd, ledctrlr.sch]
2012-10-30 working on new board design
    [ledctrlr.brd, ledctrlr.sch]
2012-11-04 rev 2.0 routed
    [ledctrlr-Back.gbl, ledctrlr-Front.gtl, ledctrlr-Mask_Back.gbs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]
2012-11-04 clean up traces, add helpful text
    [ledctrlr.brd]
2012-11-05 update boms
    [commbrd-bom.csv, commdngl-bom.csv, ledctrlr-bom.csv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]
2012-11-06 clean up routing, switch GSCLK to PB0
    [ledctrlr.brd, ledctrlr.sch]
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2012-11-07 clean up routing, return GSCLK to PD3, initial gerber export
    [ledctrlr-Back.gbl, ledctrlr-Front.gtl, ledctrlr-Mask_Back.gbs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]
2012-11-12 Add fill for VAA, update screw terminal connector.
    [ledctrlr.brd]
2012-11-15 clean up ground routing, get rid of npth
    [ledctrlr.brd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]
2012-11-15 remove npth drill file
    [ledctrlr-NPTH.drl]
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2012-11-17 clean up traces, update gerber
    [ledctrlr.brd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]
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2012-11-17 more traces cleanup, cutouts cleanup, etc.
    [ledctrlr.brd]
2012-11-17 code cleanup; fix cmdstate case not breaking
    [main.c]
2012-11-19 exported and sent to itead studios for production!
    [$ledctrlr.brd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]
2012-11-19 export of version 2.0 of acris led controller
    [$ledctrlr.brd, commbrd.csv, commdngl.csv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]
2012-11-21 manually correct bom for digikey order
    [ledctrlr-digikey.csv]
2012-12-11 Whoops, soldermask and solder paste on back led connectors were wrong
    [ledctrlr.brd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]
2012-12-11 update digikey bom
    [ledctrlr-digikey.csv]
2012-12-20 add set_led() wrapper to set an RGB LED to a color, finish command processor
2012-12-30 fix driver off by one error, initialization error
    [main.c]
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2013-01-01 get rid of old led controller firmware -- unified firmware appears to be working
2013-01-02 fix bootloader code to make it work with new unified firmware
    [main.c, main.h, pins.h]
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2013-01-15 widen VCC pins on the power port
    [ledctrlr.brd]
2013-01-15 move some silkscreen labels around to clean up the board
    [ledctrlr.brd]
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2013-10-06 add schematics and footprints for green and black NRF24L01+ modules
    [ledctrlr.brd, ledctrlr.sch]
2013-10-07 fixes for the wireless module
    [main.c]
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2013-10-08 gonna have to start routing a new board eventually
    [ledctrlr.brd]
2013-10-09 moved ledcontroller to a separate uart-based project in order to make room for development of wireless one, all projects should build atm
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2013-10-12 transmit appears to be working
    [ledctrlr.sch]
2013-10-13 clean up boards a bit
    [ledctrlr.brd, ledctrlr.sch]
2013-10-13 add ledctrlr project, which should theoretically work as a wireless comm firmware
2013-10-14 more board tweaks
    [ledctrlr.brd]
2013-10-14 tweaks to nrf test fw: addition of wait before initializing nrf, bump up uart speed and print out more characters
2013-10-14 use a stupid hack to wait for the NRF chip to be ready.
    Basically, read a register until a default bit is set. The bit must be
    set both by default from power-up and in initialization to handle both
    the system power-up and micro reset cases.
    [main.c]
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2013-10-14 remove generated board files
    [commbrd.csv, commdngl.csv, ledctrlr.csv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]
2013-10-14 Add initial Makefile for generating export files from PCBs, restructure PCB CAD layouts
    [commbrd-Back.gbl, commbrd-Front.gtl, commbrd-Mask_Back.gbs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]
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2013-10-14 now the wireless bootloader will build, but it's way too big to fit in the bl sector... this is going to be a tough issue to solve
    [main.c, main.h]
2013-10-14 tweak kicad settings a bit
    [ledctrlr.brd]
2013-10-15 wireless bootloader: enable garbage collection and cut out a lot of important stuff to meet size reqs
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2013-10-28 test-nrf: add target for real led controller board
    uses USART for SPI, doesn't attempt to printf received data
    [main.c, pins.h]
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2013-10-28 fix endianness of addresses
    [main.c]
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
